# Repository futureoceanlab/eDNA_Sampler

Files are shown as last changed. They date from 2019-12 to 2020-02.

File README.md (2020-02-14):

# eDNA Sampler
This is a project that controls an autonomous eDNA Sampler. There are two modules: ESP8266 based hardware controller and a Django Web Application for interact with ESP8266 wirelessly.

The detailed documentation on architecture, how-to-build, apparatus and testing can be found in eDNA_sampler.pdf in this repository. Furthermore, the link to view the overleaf can be found [here](https://www.overleaf.com/read/nvktmdfzfmym). Please send an email to junsuj@mit.edu if you would like to edit the documentation. 

## Current Apparatus
Feb 2020: We currently have one full-system ready to be disassembled in the lab. We have four packs of batteries and three housings with connectors ready to be assemebled. We have 9 PCB boards and required components to be soldered on the PCB.

# Overview of this repository

## webapp: Web App for online deployment configuration / data retrieval
The program is run on a virtual environment, so install the virtualenv on the machine that will run the Web App.

```bash
pip3 install virtualenv
```

In case that the virtualenv is installed in a path that is not listed (i.e. virtualenv will complain saying that there is no such command), please add the following line to the end of ~/.profile 

```bash
PATH=$PATH:$HOME/.local/bin
```

in eDNA_Sampler/webapp, enter the following line in the terminal

```bash
virtualenv env
source env/bin/activate
``` 

This should activate the virtual environment, and you are ready to install the required packages

```bash
pip3 install -r requirements.txt
```

The webserver hosts' IP address can be found at WLAN0 interface by running the following:

```bash
ifconfig
```

In the webapp directory, run the server

```bash
python3 manage.py runserver 0.0.0.0:5000
```

0.0.0.0 will listen to other devices connected through every interfaces. 5000 is the port, and it can be different as long as it does not coincide with other used ports. 

Finally, check the Firewall if the client cannot access the webapp.

## sampler_mcu: ESP8266 Based Arduino code
The system uses ESP8266 Huzzah from Adafruit and a variety of libraries, and thus, Arduino IDE requires some setup.

In particular, the libraries that need to be installed are:
[ESP8266](https://learn.adafruit.com/adafruit-huzzah-esp8266-breakout/using-arduino-ide), 
[GrooveNfc](https://github.com/Seeed-Studio/Seeed_Arduino_NFC), 
ArduinoJson,
[MS5837](https://github.com/bluerobotics/BlueRobotics_MS5837_Library), 
[TSYS01](https://github.com/bluerobotics/BlueRobotics_TSYS01_Library).

[ESP8266 Huzzah](https://learn.adafruit.com/adafruit-huzzah-esp8266-breakout/using-arduino-ide) explains how to program the device using FTDI converter.

## mechanical
This directory contains designs and schematics for mechanical components of the eDNA Sampler.
Specifically, we have 3D design of the battery housing and acrylic plates for the pvc clamp shell. 
There is also the electronics housing drawing for machining.

## pcb
This is the schematic and layout of the PCB design of the electronics.

## archive
This is a folder with ancient codes and files that were onced developed. They are irrelevant at this point, but archived in this folder.

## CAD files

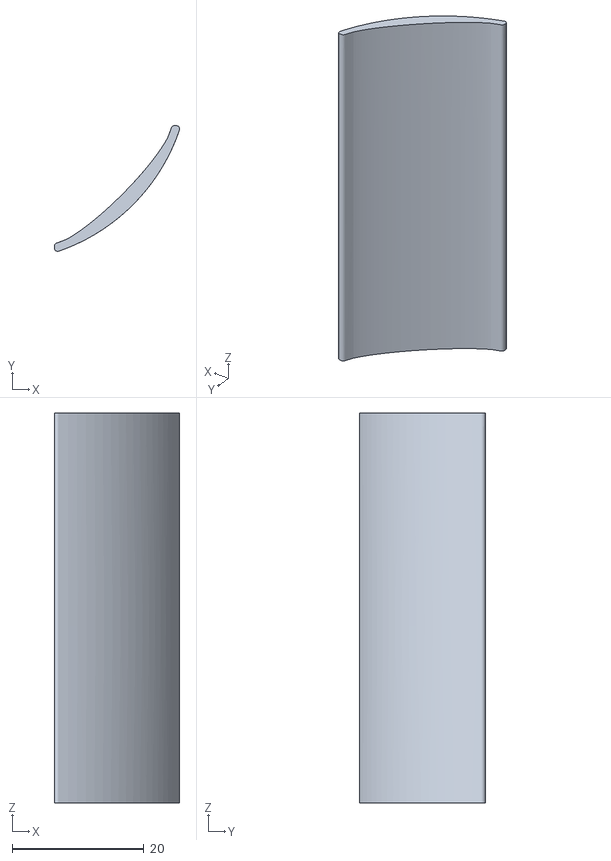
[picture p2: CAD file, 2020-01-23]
mechanical/battery/v4/Cover.stl
19.0 x 19.1 x 59.1

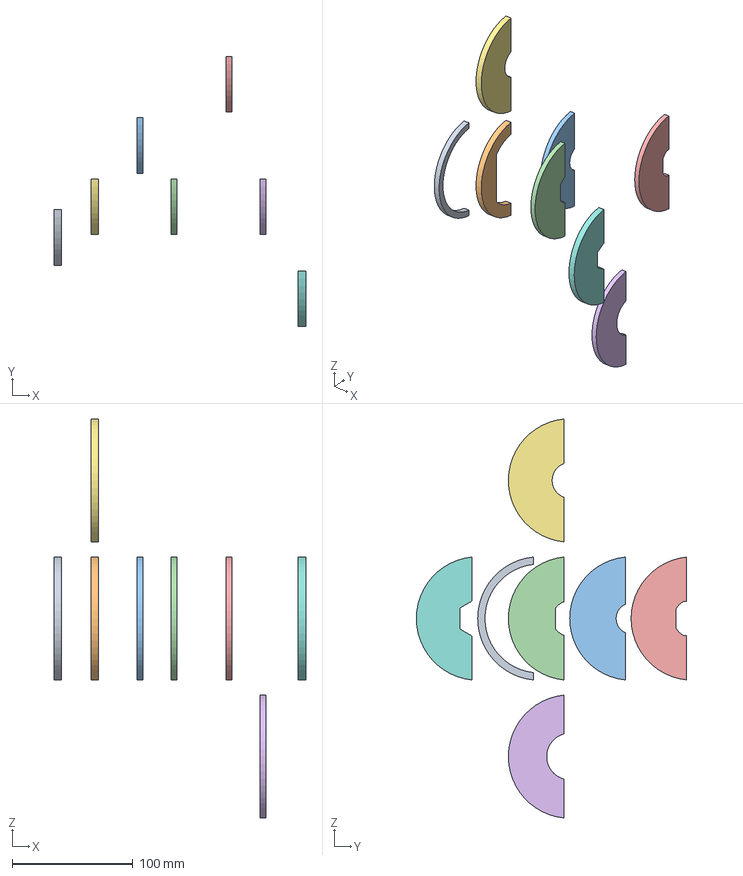
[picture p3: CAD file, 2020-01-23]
mechanical/pvc_shell/PVC_holders v5.step
208.3 x 223.9 x 330.4 mm
range
potted1
connector1
connector2
connector3
connector4
connector2_2
connector4_2

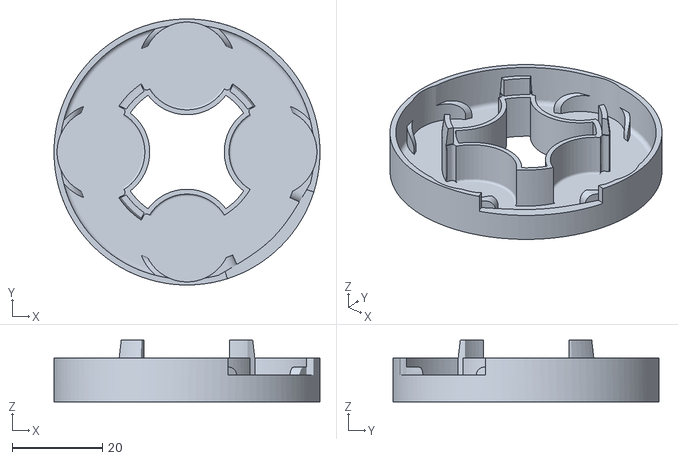
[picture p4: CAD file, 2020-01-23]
mechanical/battery/v4/Battery Cap Bottom.stl
58.9 x 58.9 x 13.7

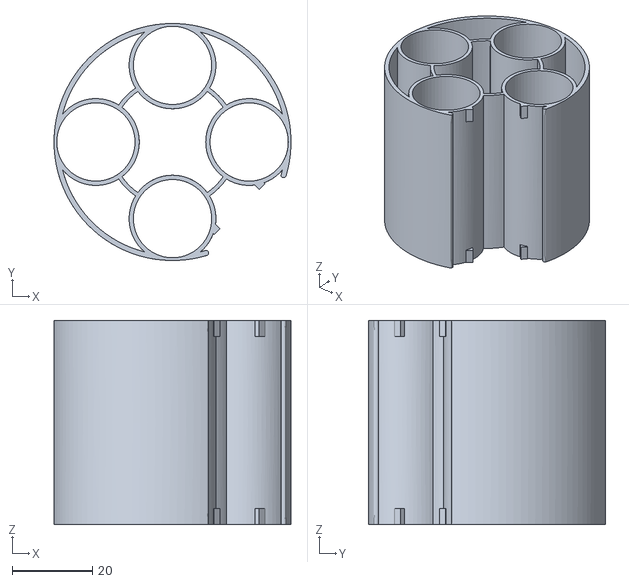
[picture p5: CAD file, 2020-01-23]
mechanical/battery/v4/Battery Holder.stl
58.9 x 58.9 x 50.8

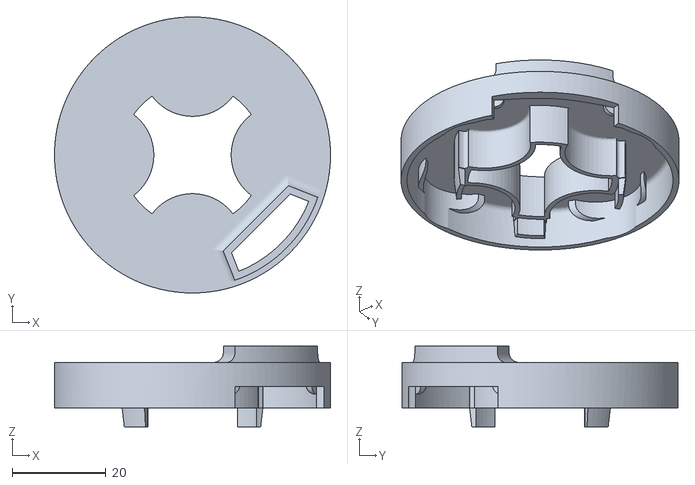
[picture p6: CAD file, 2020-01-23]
mechanical/battery/v4/Battery Cap Top.stl
58.9 x 58.9 x 17.2

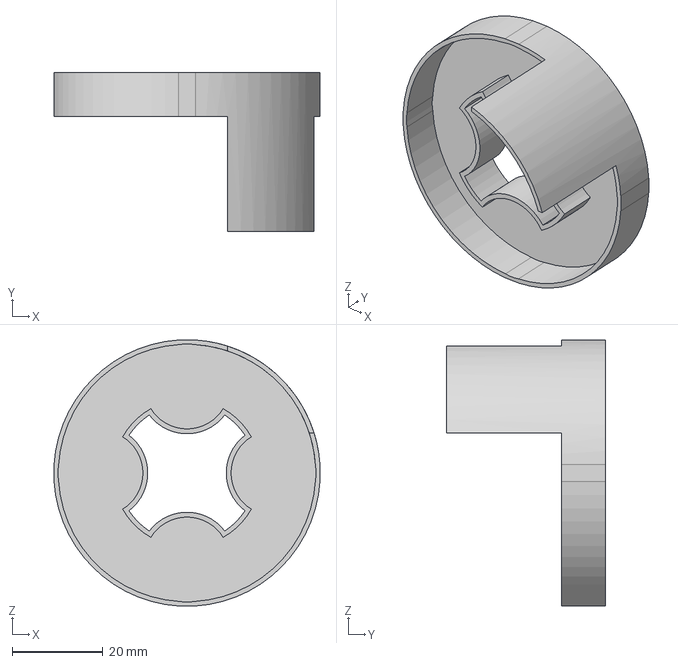
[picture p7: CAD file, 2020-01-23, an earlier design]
mechanical/battery/v3/batter bottom cap.step
58.6 x 35.1 x 58.6 mm

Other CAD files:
mechanical/battery/v3/battery top cap.step
mechanical/battery/v3/batter holder v3.step

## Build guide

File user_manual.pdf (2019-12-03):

Deployment Procedure
Phase 1: setting up the deployment
1. Make sure that the RPI is powered on
2. Plug in the RFID Reader dongle
3. The data from the previous deployment will have been uploaded
4. When the blue light blinks, tap the RFID on the filter onto the antenna
5. By now, the log from the previous deployment will have been uploaded
6. Wait until that green light blinks
7. Refresh the website, then the new deployment with corresponding RFID UID will appear
8. Click on “edit” next to the UID
9. Follow the instruction and specify the deployment details
10. Click “Submit” button at the bottom
11. Wait until the green light stops blinking. At this point, the sampler is properly programmed!
12. Pull out the RFID Reader dongle and wait until deployment
Phase 2: deployment
1. Make sure that the RPI is powered on
2. Plug in the pump unit and wait until the green light is on
3. Deploy!

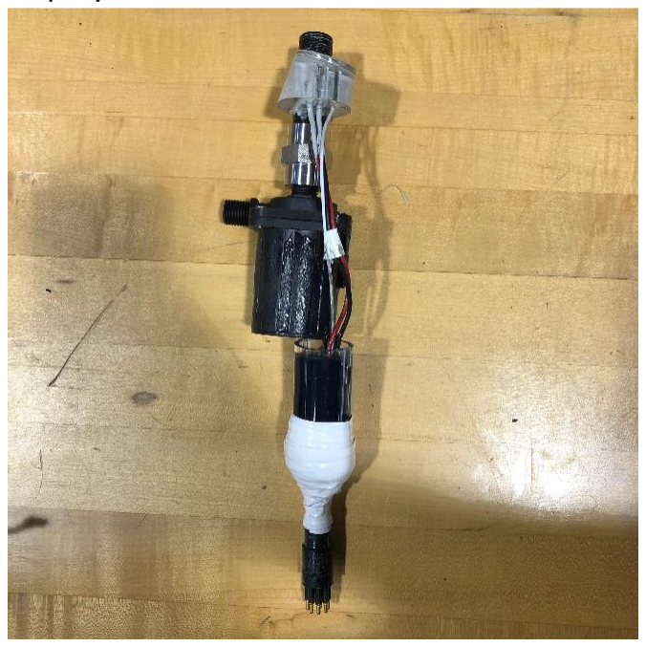
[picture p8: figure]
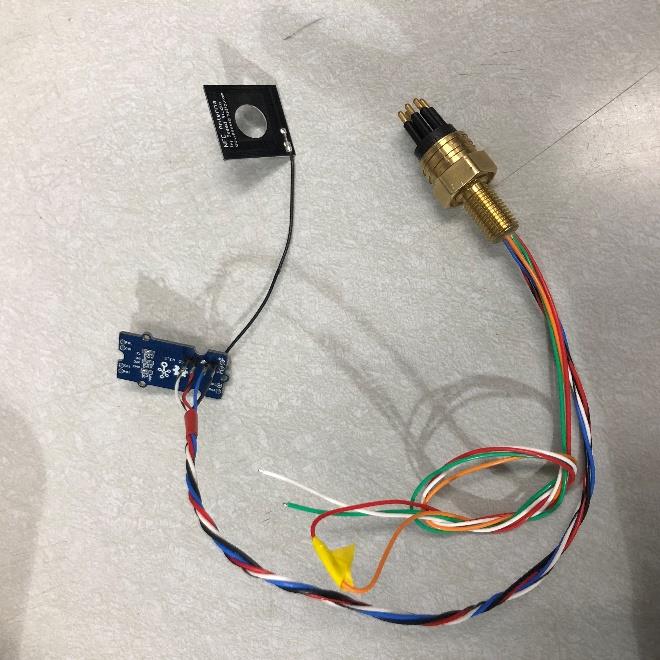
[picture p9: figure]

The pump unit | RFID reader dongle
Notes
- When the RFID reader cannot be properly initialized, which happens quite frequently, it restarts the entire system. It is fine, but you will notice the repeated sequence of the following light actions: blue sparks (turned on), red blinks (set-up), then turn off (failed reader initialization). It will power-cycle until blue light blinks (reader initialized), so please be patient! Unfortunately, we are stuck with this reader for now.
- To re-charge the battery, please plug in the recharging dongle.
- When all three LEDs blink together, something has gone awry in the code as it was setting things up (e.g. I2C devices or WiFi). In this case, please power-cycle by re-plugging in the dongle. The failure will be logged in /log.txt, which will be uploaded the next time it connects to the WiFi.
- Please be aware that there will be some water that flows as the device is primed in water. Hence, using distilled water first is recommended…!

Appendix 1: Programming the ESP8266 HUZZAH

Clone the github repository: https://github.com/futureoceanlab/eDNA_Sampler.git

Please install Arduino IDE and required libraries mentioned in the github.

Upon plugging in the serial cables as shown above, you'll need to put the board into bootload mode. You'll have to do this before each upload. Each button is labeled in the image above.
1. Hold down the GPIO0 button, the red LED will be lit
2. While holding down GPIO0, click the RESET button
3. Release RESET, then release GPIO0
4. When you release the RESET button, the red LED will be lit dimly, this means it's ready to bootload

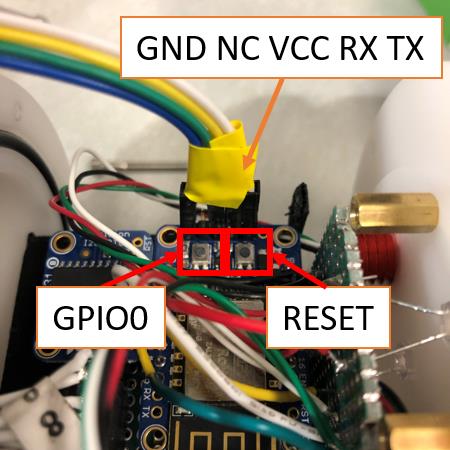
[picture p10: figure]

Now you can upload the code using Arduino IDE

Appendix 2: Programming the webserver (RPI)

Clone the github repository: https://github.com/futureoceanlab/eDNA_Sampler.git

Modify the first line of run_webserver.sh to match the location of the cloned git repository.

Add a line at th end of the following file /etc/rc.local
“sudo bash /home/pi/eDNA_Sampler/run_webserver.sh &”
This should automatically run webserver when the RPI turns on

To set up the RPI to host its own WiFi, follow the instruction until before “add routing and masquerade” section in this link: https://www.raspberrypi.org/documentation/configuration/wireless/access-point.md

ESP8266’s are programmed to look for 192.168.4.1:5000, which is the ip-address and ports of the RPI webserver to access the web application. If that is different, ESP8266 will have to be re-programmed.

# eDNA Sampler Checklist

## Phase 1: Setting up the deployment

1 | Make sure that the RPI is powered on
2 | Plug in the RFID reader dongle
3 | When the blue light blinks, tap the RFID tag on the filter onto the reader antenna
4 | Wait until the green light blinks
5 | Refresh the website
6 | Click on “edit” next to the new UID added
7 | Follow the instruction and specify the deployment details
8 | Click on “submit” button
9 | Wait until the green light stops blinking
10 | Pull out the RFID reader dongle

## Phase 2: Deployment

1 | Make sure that the RPI is on
2 | Plug in the pump unit
3 | Wait until the green light is on
4 | Deploy!

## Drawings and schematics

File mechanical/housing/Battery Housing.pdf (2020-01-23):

A

2 | 3 | 4 | 5 | 6 | 7 | 8

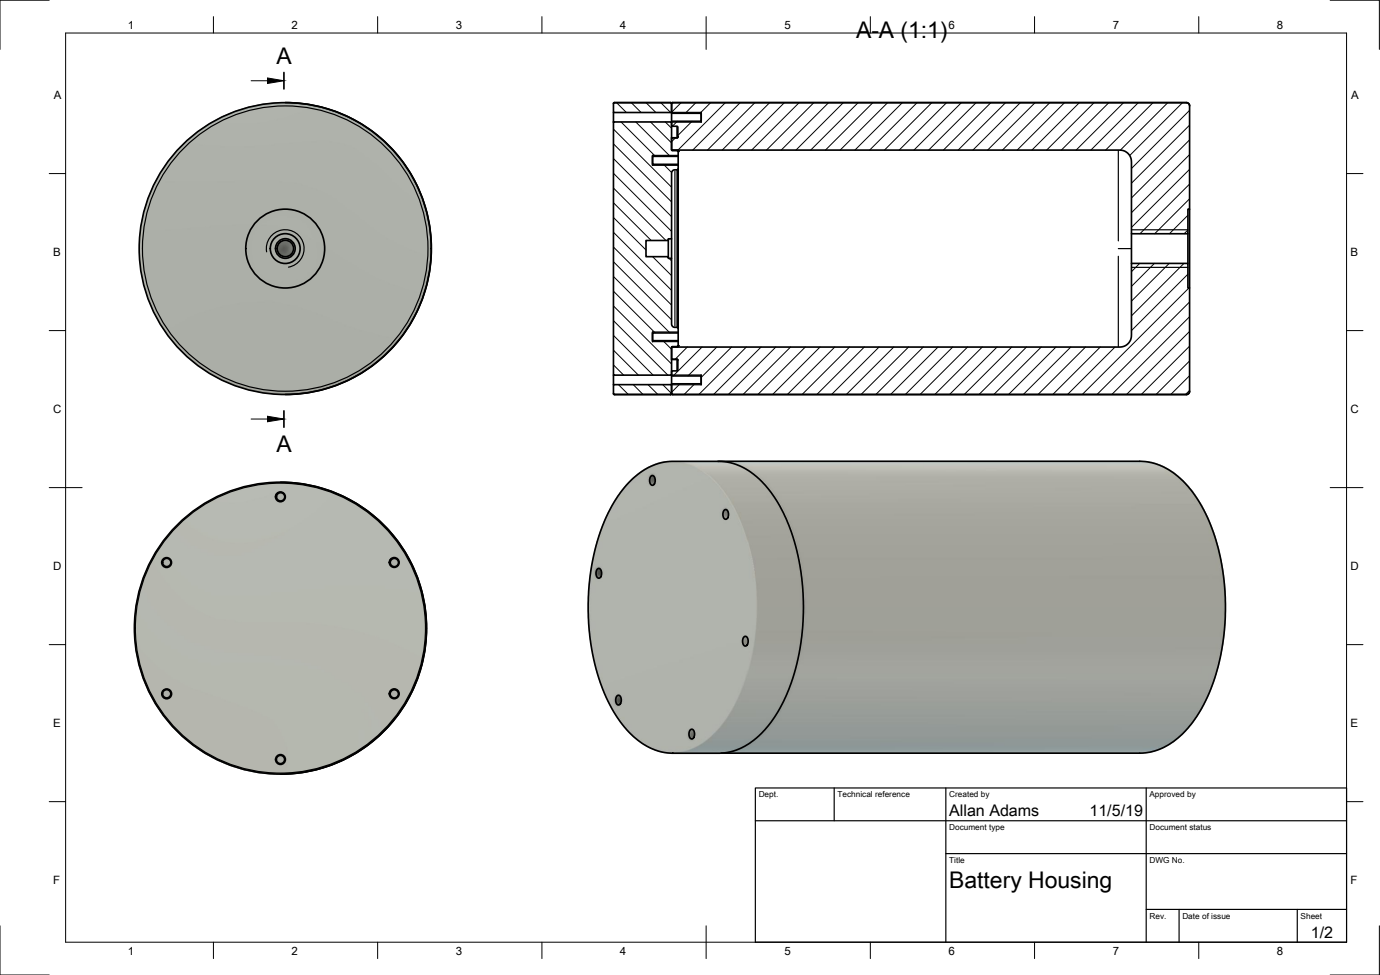
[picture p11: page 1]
Dept.; Technical reference; Created by; Approved by; Document type; Document status; Allan Adams

Title Battery Housing | DWG No.

Rev. | Date of issue | Sheet

A

A

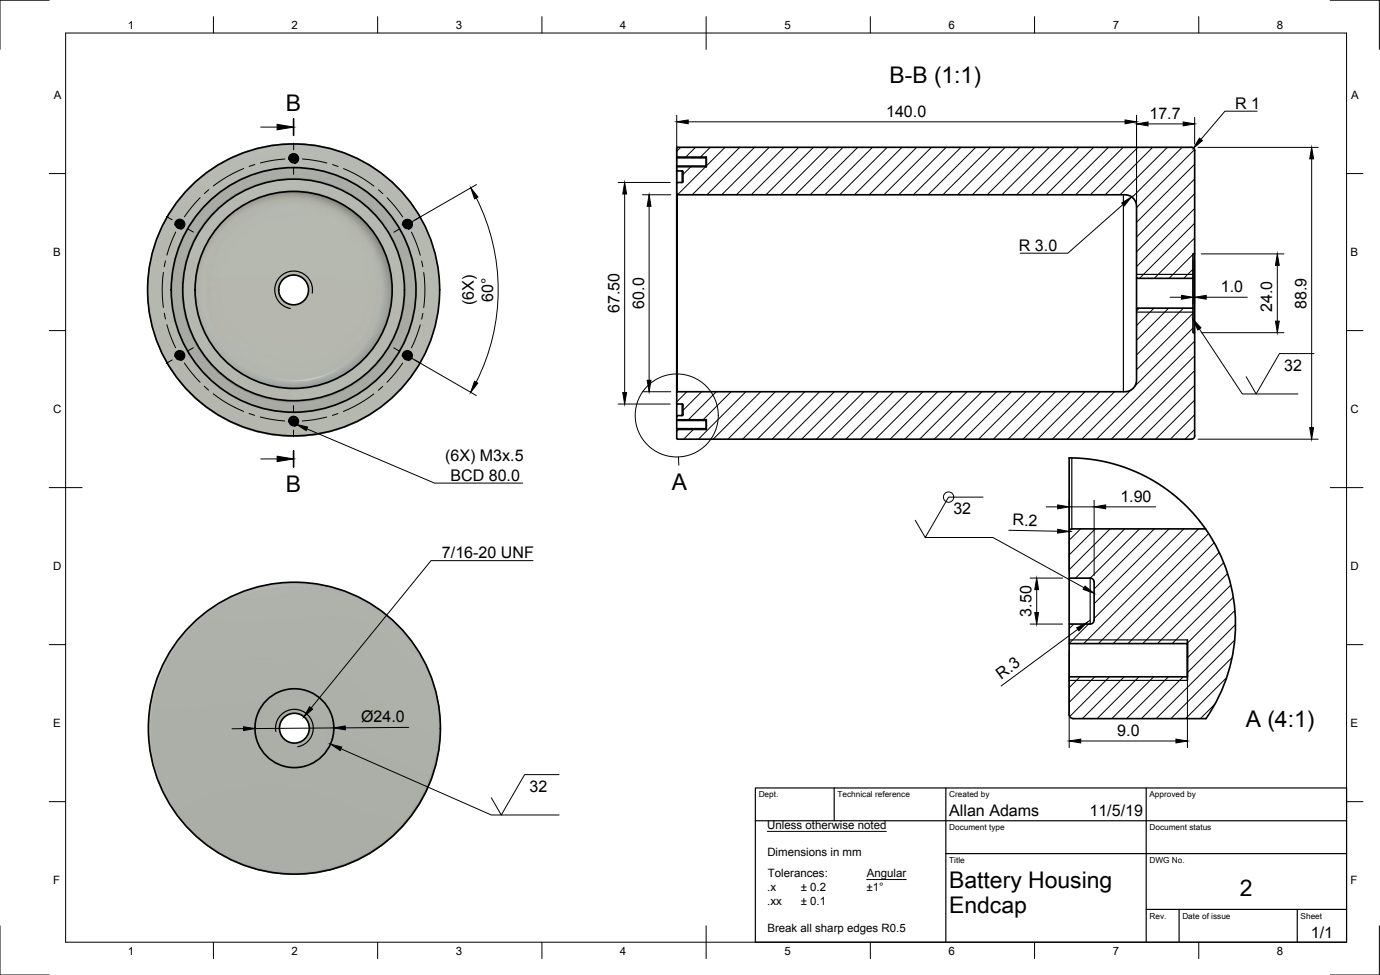
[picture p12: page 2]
Dept.; Technical reference; Created by; Approved by; Document type; Document status; Title; DWG No.; Endcap; 2 Battery Housing; Allan Adams; 7/16-20 UNF; (6X) M3x.5 BCD 80.0; Tolerances:; Angular

Unless otherwise noted

Dimensions in mm

Break all sharp edges R0.5

A

A

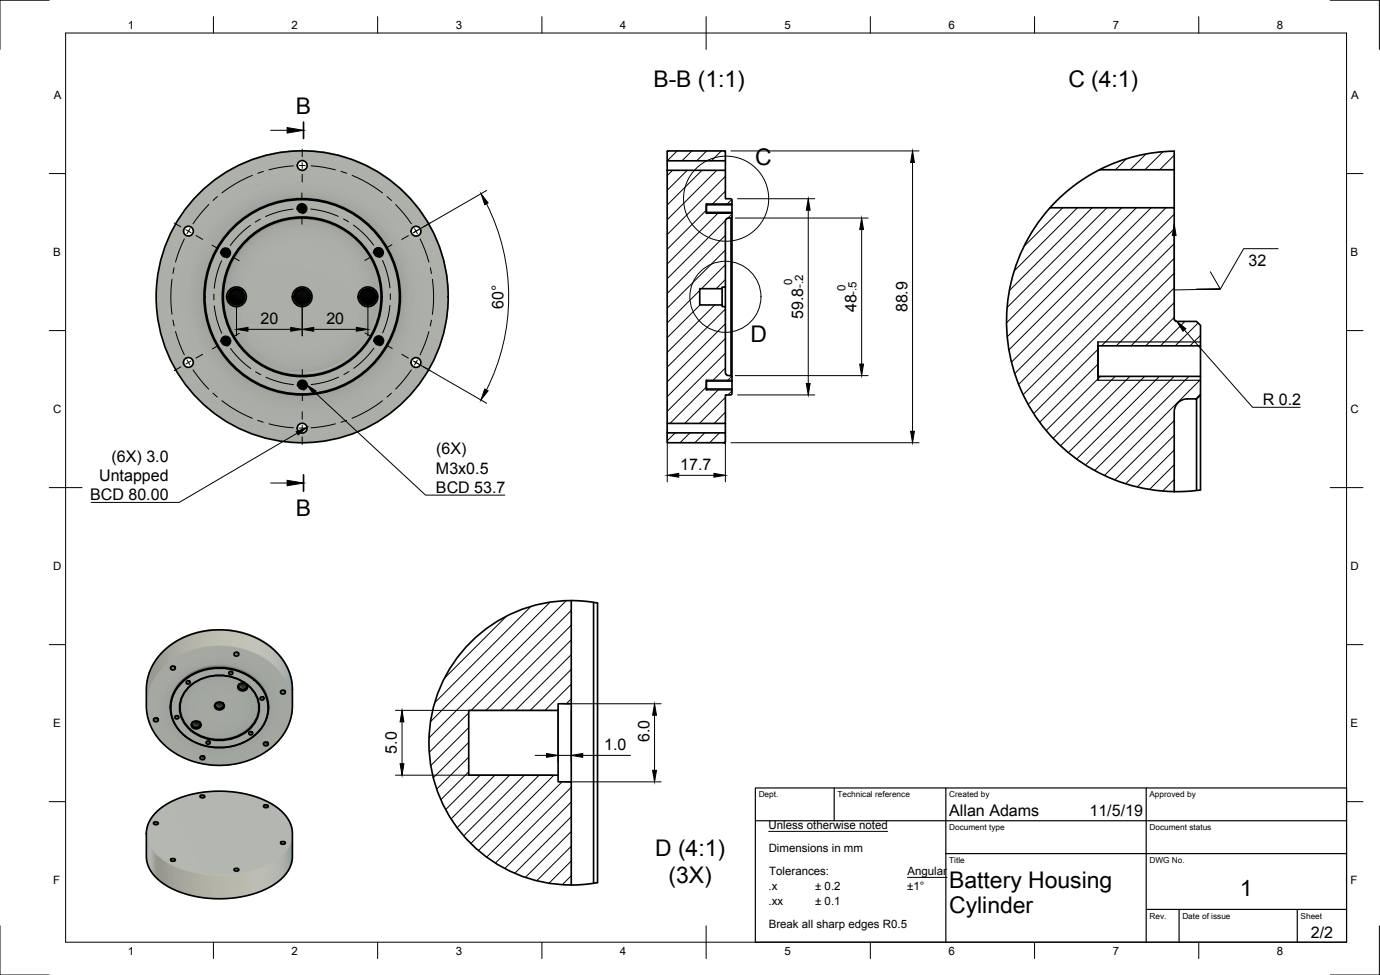
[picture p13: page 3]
Dept.; Technical reference; Created by; Approved by; Document type; Document status; Title; DWG No.; Cylinder; 1 Battery Housing; Allan Adams; (6X) M3x0.5 BCD 53.7; (6X) 3.0 Untapped BCD 80.00; Tolerances:; Angular

Unless otherwise noted
Dimensions in mm
Break all sharp edges R0.5

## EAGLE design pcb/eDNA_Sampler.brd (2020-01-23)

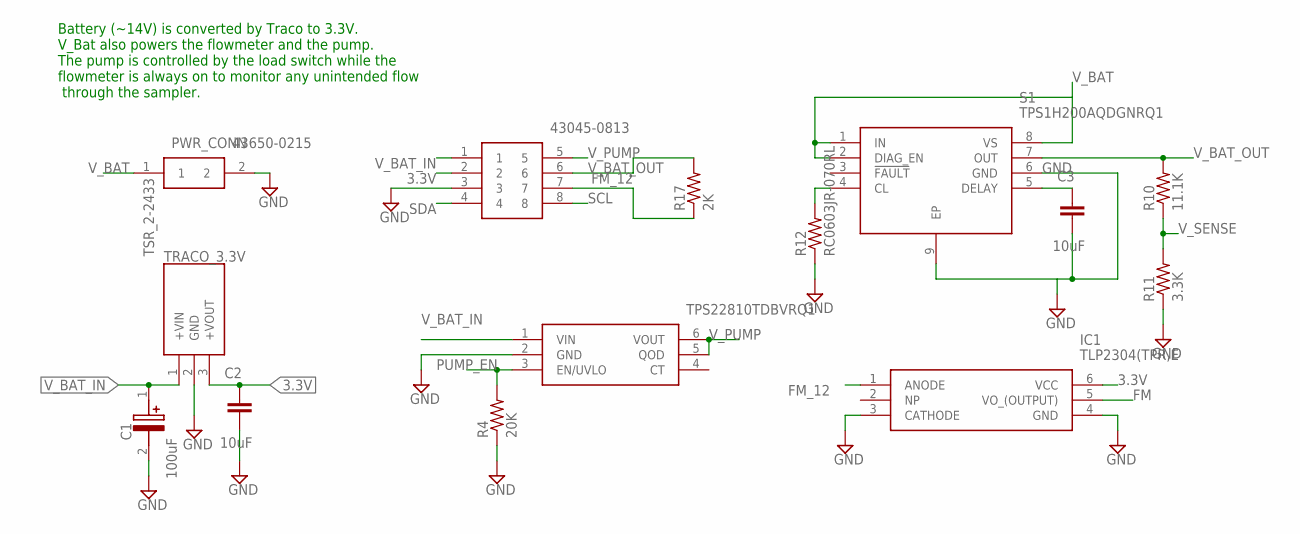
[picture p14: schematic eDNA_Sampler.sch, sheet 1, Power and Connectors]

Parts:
C1: 100uF; CAPPRD250W50D680H1250
C2, C3: 10uF; CAP_0603
IC1: TLP2304(TPR,E; SOIC127P700X230-6N
LOAD_SWITCH: TPS22810TDBVRQ1; SOT95P280X145-6N
PENETRATOR_CONN: 43045-0813
PWR_CONN: 43650-0215; 43650-0217
R4: 20K; RES_0603
R10: 11.1K; RES_0603
R11: 3.3K; RES_0603
R12: RC0603JR-070RL; RES_0603
R17: 2K; RES_0603
S1: TPS1H200AQDGNRQ1; SOP65P490X110-9N
TRACO_3.3V: TSR_2-2433; TSR-2

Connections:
3.3V: C2.1, IC1.6 (VCC), PENETRATOR_CONN.2, TRACO_3.3V.3 (+VOUT); also elsewhere on the board
FM: IC1.5 (VO_(OUTPUT)); also elsewhere on the board
FM_12: IC1.1 (ANODE), PENETRATOR_CONN.7, R17.1
GND: C1.2 (-), C2.2, C3.2, IC1.3 (CATHODE), IC1.4 (GND), LOAD_SWITCH.2 (GND), PENETRATOR_CONN.3, PWR_CONN.2, R4.1, R11.1, R12.1, S1.6 (GND), S1.9 (EP), TRACO_3.3V.2 (GND); also elsewhere on the board
unnamed: R12.2, S1.4 (CL)
unnamed: C3.1, S1.5 (DELAY)
PUMP_EN: LOAD_SWITCH.3 (EN/UVLO), R4.2; also elsewhere on the board
SCL: PENETRATOR_CONN.8; also elsewhere on the board
SDA: PENETRATOR_CONN.4; also elsewhere on the board
V_BAT: PWR_CONN.1, S1.1 (IN), S1.2 (DIAG_EN), S1.8 (VS)
V_BAT_IN: C1.1 (+), LOAD_SWITCH.1 (VIN), PENETRATOR_CONN.1, TRACO_3.3V.1 (+VIN)
V_BAT_OUT: PENETRATOR_CONN.6, R10.2, R17.2, S1.7 (OUT)
V_PUMP: LOAD_SWITCH.5 (QOD), LOAD_SWITCH.6 (VOUT), PENETRATOR_CONN.5
V_SENSE: R10.1, R11.2; also elsewhere on the board

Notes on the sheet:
Battery (~14V) is converted by Traco to 3.3V. V_Bat also powers the flowmeter and the pump. The pump is controlled by the load switch while the flowmeter is always on to monitor any unintended flow through the sampler.

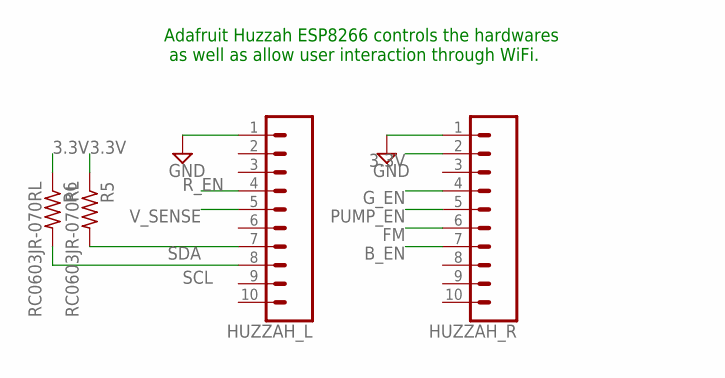
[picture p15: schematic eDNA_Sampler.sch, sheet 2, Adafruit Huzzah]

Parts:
HUZZAH_L: CONN_10"; 1X10
HUZZAH_R: CONN_10"; 1X10
R5, R6: RC0603JR-070RL; RES_0603

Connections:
3.3V: HUZZAH_R.2, R5.1, R6.1; also elsewhere on the board
B_EN: HUZZAH_R.7; also elsewhere on the board
FM: HUZZAH_R.6; also elsewhere on the board
GND: HUZZAH_L.1, HUZZAH_R.1; also elsewhere on the board
G_EN: HUZZAH_R.4; also elsewhere on the board
PUMP_EN: HUZZAH_R.5; also elsewhere on the board
R_EN: HUZZAH_L.4; also elsewhere on the board
SCL: HUZZAH_L.8, R6.2; also elsewhere on the board
SDA: HUZZAH_L.7, R5.2; also elsewhere on the board
V_SENSE: HUZZAH_L.5; also elsewhere on the board

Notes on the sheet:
Adafruit Huzzah ESP8266 controls the hardwares as well as allow user interaction through WiFi.

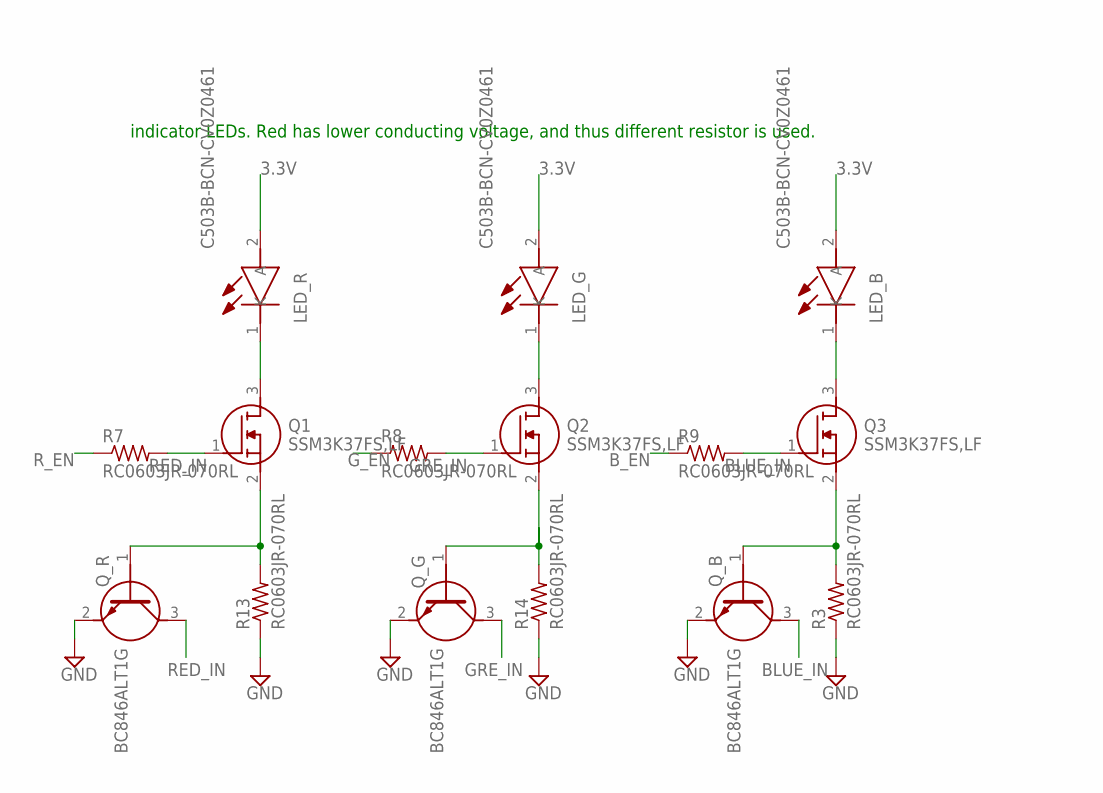
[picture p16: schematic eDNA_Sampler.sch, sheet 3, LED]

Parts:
LED_B: C503B-BCN-CV0Z0461; C503B-BCN
LED_G: C503B-BCN-CV0Z0461; C503B-BCN
LED_R: C503B-BCN-CV0Z0461; C503B-BCN
Q1, Q2, Q3: SSM3K37FS,LF; SSM3K37FSLF
Q_B: BC846ALT1G; SOT95P237X111-3N
Q_G: BC846ALT1G; SOT95P237X111-3N
Q_R: BC846ALT1G; SOT95P237X111-3N
R3, R7, R8, R9, R13, R14: RC0603JR-070RL; RES_0603

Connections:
3.3V: LED_B.2 (A), LED_G.2 (A), LED_R.2 (A); also elsewhere on the board
BLUE_IN: Q3.1 (G), Q_B.3 (C), R9.2
B_EN: R9.1; also elsewhere on the board
GND: Q_B.2 (E), Q_G.2 (E), Q_R.2 (E), R3.1, R13.1, R14.1; also elsewhere on the board
GRE_IN: Q2.1 (G), Q_G.3 (C), R8.2
G_EN: R8.1; also elsewhere on the board
unnamed: LED_R.1 (K), Q1.3 (D)
unnamed: LED_G.1 (K), Q2.3 (D)
unnamed: Q2.2 (S), Q_G.1 (B), R14.2
unnamed: Q1.2 (S), Q_R.1 (B), R13.2
unnamed: Q3.2 (S), Q_B.1 (B), R3.2
unnamed: LED_B.1 (K), Q3.3 (D)
RED_IN: Q1.1 (G), Q_R.3 (C), R7.2
R_EN: R7.1; also elsewhere on the board

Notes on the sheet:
indicator LEDs. Red has lower conducting voltage, and thus different resistor is used.

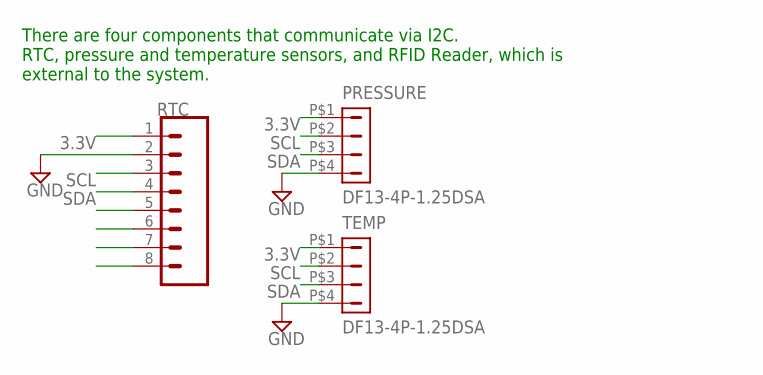
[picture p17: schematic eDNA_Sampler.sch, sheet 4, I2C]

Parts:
PRESSURE: DF13-4P-1.25DSA
RTC: CONN_08"; 1X08
TEMP: DF13-4P-1.25DSA

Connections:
3.3V: PRESSURE.P$1 (1), RTC.1, TEMP.P$1 (1); also elsewhere on the board
GND: PRESSURE.P$4 (4), RTC.2, TEMP.P$4 (4); also elsewhere on the board
SCL: PRESSURE.P$2 (2), RTC.3, TEMP.P$2 (2); also elsewhere on the board
SDA: PRESSURE.P$3 (3), RTC.4, TEMP.P$3 (3); also elsewhere on the board

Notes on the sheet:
There are four components that communicate via I2C. RTC, pressure and temperature sensors, and RFID Reader, which is external to the system.

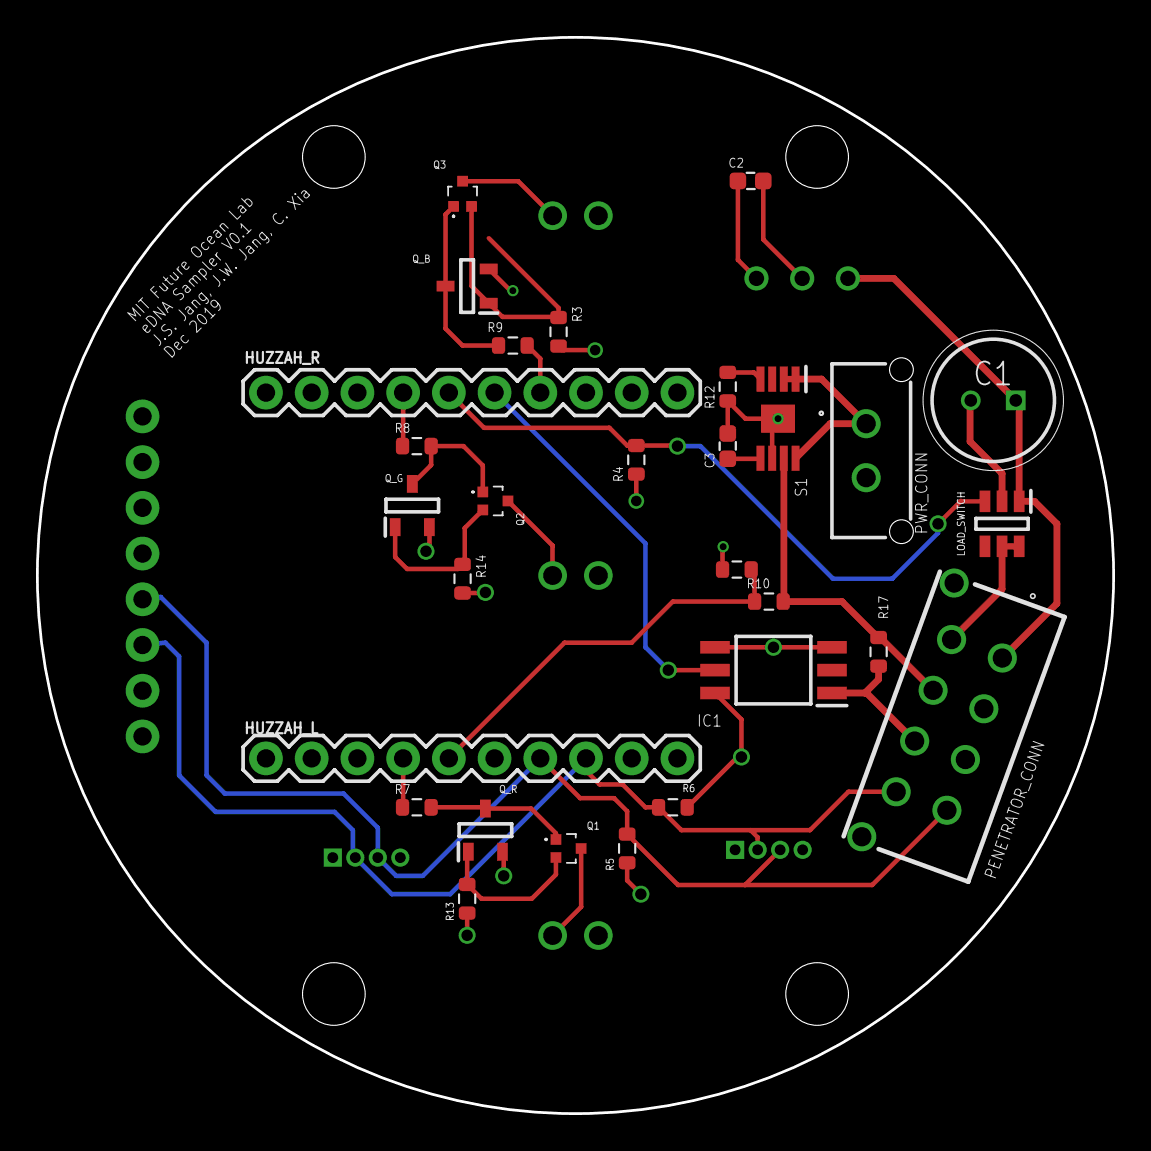
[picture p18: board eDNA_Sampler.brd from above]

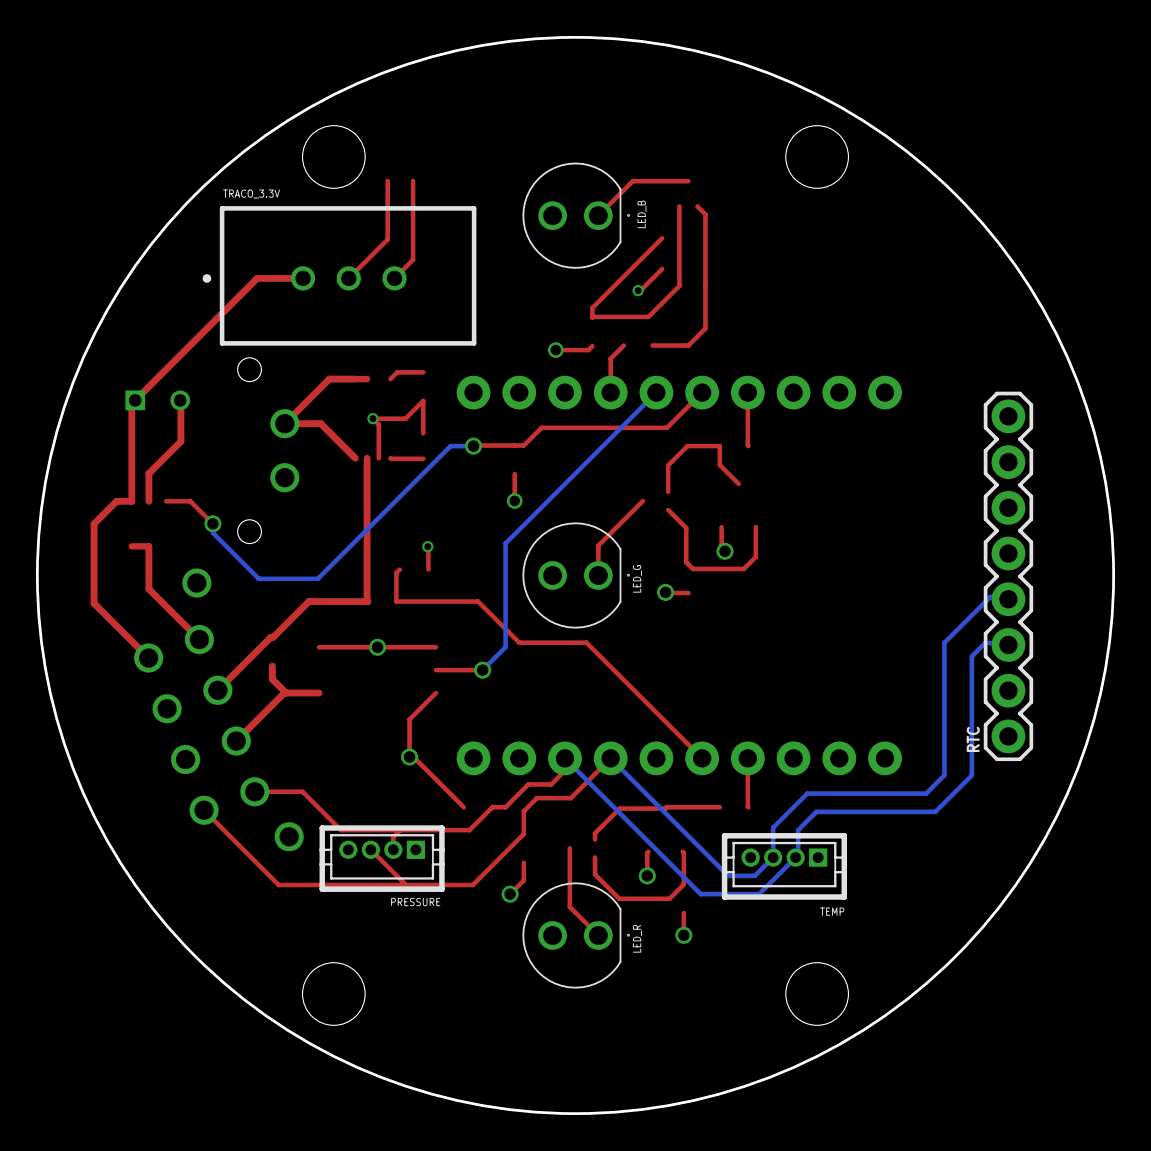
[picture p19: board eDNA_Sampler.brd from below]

Board: 4 copper layers, 59.8 x 59.8 mm, 36 parts (7 on the bottom side), 26 nets.

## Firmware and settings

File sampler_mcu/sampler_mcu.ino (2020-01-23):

/**
 * eDNA Sampler: ESP8266 based eDNA sampler / relevant sensor controller
 * January 2020
 * Authors: JunSu Jang
 *        
 *      [Descriptions]
 * 
 *  This eDNA Sampler will sample eDNA at specified depth of the ocean by
 * using a off-the-shelf pump. It keeps track of the relevant data 
 * (i.e. pressure, temperature, water flow and realtime)
 * 
 * 1. Deployment configuration
 *  a) Set up I2C devices (RTC, RFID reader, pressure and temperature sensors)
 *  b) Connect to local WiFi and upload collected data if exists
 *     Delete the uploaded datafile
 *  c) Wait for a eDNA filter's RFID tag to be tagged
 *  d) Upon tagging, create a deployment on the local webserver and
 *     wait for deployment configurations
 * 
 *     Pump Starting Conditions
 *     i) "Target Depth" (meters)
 *        - Pump at this depth within the "Depth Band"
 *     ii) "Target Temperature" (Celcius)
 *        - Pump in this thermocline within the "Temperature Band"
 *     iii) "Wait Time" upon 2m submersion (minutes):
 *        - Depending on the deployment, it may not reach the depth, 
 *          in which case, we start pumping after "Wait Time"
 *
 *     Pump Terminate Conditions
 *     i) "Target Flow Volume" (Liter)
 *        - We will pump water until target volume has been passed 
 *          through the filter
 *     ii) "Minimum Flowrate" (Liters/min)
 *        - Stop when the filter is clogged
 *     iii) "Target Flow Duration" (minutes)
 *        - Our filter may be full before the target volume has been met. 
 *          We stop pumping after specified "Target Flow Duration"
 * 2. Start logging time, pressure, temperature, volume and flowrate at 1Hz and
 *    log it to the file created
 * 3. Control the pump according to the configuration provided
 * 4. Keep measure flow, time, pressure and temperature at 1Hz until the power is off
 * 
 *      [LED Encoding]
 * 
 * - Power on --> RED on
 * - Wait for RFID --> BLUE blink
 * - Wait for deployment config --> GREEN blink
 * - All ready -- GREEN on
 * 
 *      [SPIFFS data filesystem]
 * 
 * Filename: [RFID_UID].txt
 * Logged data: [unix timestamp],[pressure],[temperature],[volume],[flowrate]\r\n
 * There is also an intenral log file that allows users to debug any issues
 * during deployment. 
*/

// Native libraries
#include <Wire.h>
#include <Ticker.h>
#include <String.h>
#include <FS.h>
#include <NfcAdapter.h>
#include <PN532/PN532/PN532.h>
#include <PN532/PN532_I2C/PN532_I2C.h>
#include <ArduinoJson.h>
#include <limits.h>
// External libraries
#include "TimeLib.h"
#include "RTClib.h"
#include "MS5837.h"
#include "KellerLD.h"
#include "TSYS01.h"
// Custom libraries
#include "src/sampler.h"                // verifies conditions for pump control
#include "src/samplerHelper.h"          // helper functions
#include "src/samplerWiFi.h"            // module that handles WiFi connection/comms
#include "src/samplerGlobals.h"         // contains all of the global variables

/**
 *  Data variables
 */
// Flowmeter
volatile uint32_t flowCounter = 0;  // flowmeter interrupt update variable
volatile uint32_t curTicks = 0;     // Stamped number of accumulated flowmeter ticks 
volatile uint32_t curTime;          // current time
float curDepth = 0.f;               // depth in meters
float curTemperature = 0.f;         // temperature in Celcius
float curFlowrate = 0.f;            // flowrate in L/min

/**
 * Peripherals
 */
// RTC
RTC_DS3231 rtc;
// Pressure
#ifdef IS_MS5837
MS5837 pSensor;
#else // Keller Sensor
KellerLD pSensor;
#endif
// Temperature
TSYS01 tSensor;
// RFID
PN532_I2C pn532_i2c(Wire);
NfcAdapter rfidReader = NfcAdapter(pn532_i2c);
String eDNA_UID;                    // UID of the RFID tag attached to sampler
// Timer for 1Hz log / LED
Ticker ticker;
// Pump
uint32_t pumpDuration = 0;          // number of seconds after pump started
                                    // to calculate initial pump max. flowrate

/**
 *  flags
 */
uint8_t fSamplerStatus = NOT_READY;
uint8_t fPumpStatus = IDLE;
uint8_t fLogData = NOT_READY;

/**
 *  Logger
 */
String dataFilePath;
String logFilePath = "/log.txt";

/**
 *  Sampler helper instance declaration
 */
Sampler sampler = Sampler();
SamplerWiFi samplerWiFi = SamplerWiFi();

/**
 * Helper function declartions
 */
// setup relevant GPIO pins
void setupPins(void);
// Setup I2C devices
void setupI2c(void);

// Flowmeter Interrupt handler
static void ICACHE_RAM_ATTR isr_flowmeter(void);
// stamp the current flowmeter reading and time
void stampTicks(void);
// read all the peripheral data and store them in global curX variables
void readData(void);
// write the data onto the data file
void writeData(void);

// Wait for RFID to be read and set the eDNA_UID
void waitRFID(void);
// Control the pump action based on the conditions
void controlPump(void);

// synchornize the RTC with the time of the webserver
void synchronizeRTC(void);
// Check if deployment has been configured (i.e. RFID scanned)
uint8_t getDeploymentStatus(void);
// Query the deployment configuration from the webserver
void getDeploymentConfiguration(void);
// Upload data file, broken into chunks, to the webserver
void uploadExistingData(void);
// Similarly, upload log file
void uploadExistingLog(void);
// Helper function to concat data file path String
String createDataFilePath(void);

// Trigger the ticker to measure data every second
void startMeasuringData(void);
// line to log internally any information
void internalLogLine(String logData);
// Wrapper for outputing the message to the correct output
void outputDebugMessage(String msg);


/**
 *     setup()
 * 
 *   Setup GPIO Pins
 *   Setupt I2C
 *   Connect to WiFi
 *   If there is file, send it over and delete
 *   Wait for RFID
 *   Wait for Deployment configuration
 *   Create file
 *   Start collecting data
 *   
 * 
 */
void setup() {
    #ifdef DEBUG
    Serial.begin(9600);
    #endif
    SPIFFS.begin();

    setupPins();
    turnOnLED(LED_PWR);
    outputDebugMessage("Trying to connect to WiFi");
    uint8_t online = samplerWiFi.connectWiFi();
    if (!online) {
        internalLogLine("Wifi connection failed after 10 attempts!");
        flagErrorLED();
    }
    outputDebugMessage("WiFi connected");
    outputDebugMessage("Setting up I2C...");
    
    setupI2c();
    synchronizeRTC();
    uploadExistingData();
    uploadExistingLog();
    fSamplerStatus = getDeploymentStatus();

    switch (fSamplerStatus) {
        case NOT_READY:
            rfidReader.begin();
            blinkSingleLED(LED_RDYB, 500);
            waitRFID();
            turnOnLED(LED_RDYB);
            samplerWiFi.uploadNewDeployment(eDNA_UID);
            turnOffLED(LED_RDYB);
            blinkSingleLED(LED_RDYG, 500);
            getDeploymentConfiguration();
            break;
        case READY:
            blinkSingleLED(LED_RDYG, 500);
            getDeploymentConfiguration();
            dataFilePath = createDataFilePath();
            startMeasuringData();
            outputDebugMessage("Wait for deployment...");
            break;
        default:
            break;
    }
    turnOnLED(LED_RDYG);
}

/***********************************************************
 * 
 *     loop()
 * 
 *   If log data flag is set, do the following:
 *    - read from sensors
 *    - Save the data
 *   Depending on famplerStatus, act accordingly
 *   READY:
 *      Waiting to be deployed underwater (below 2m)
 *   DEPLOYED:
 *      Control the pump until surface out of the water (above 2m)
 *   COMPLETE:
 *      Out of water, just log the data until powered off
 * 
 */
void loop() {
    // Log data and check device status/action every second
    if (fLogData == READY) {
        readData();
        writeData();
        fLogData = NOT_READY;
        switch (fSamplerStatus) {
            case READY:
                #ifdef DEBUG
                sampler.setDiveStartTime(curTime);
                fSamplerStatus = DEPLOYED;
                outputDebugMessage("Deployed");
                #else
                if (curDepth > MIN_DEPTH) {
                // Finally, the device is submerged underwater!
                    sampler.setDiveStartTime(curTime);
                    // Turn off all of the LEDs in the water
                    turnOffLED(LED_PWR);
                    turnOffLED(LED_RDYG);
                    fSamplerStatus = DEPLOYED;
                }
                #endif
                break;
            case DEPLOYED:
                controlPump();
                #ifndef DEBUG
                if (curDepth <= MIN_DEPTH) {
                // Out of the water
                    fSamplerStatus = COMPLETE;
                    // Turn the LEDs back on
                    turnOnLED(LED_PWR);
                    turnOnLED(LED_RDYG);
                    // Turn off the pump just in case
                    digitalWrite(PUMP_PIN, LOW);
                }
                #endif
                break;
            case COMPLETE:
            // Nothing to do here but wait until power-cycled to upload
            // the newly collected data
                break;
            default:
                break;
        }
    }
}

void readData() {
    sampler.updateCurrentFlowrate(curTicks);
    curFlowrate = sampler.getCurFlowrate();
    // Pressure / Depth
    pSensor.read();
    curDepth = pSensor.depth();
    // Temperature
    tSensor.read();
    curTemperature  = tSensor.temperature();
}

void writeData() {
    // Write data to the data log file
    File dataFile = SPIFFS.open(dataFilePath, "a+");
    dataFile.print(curTime);
    dataFile.print(',');
    dataFile.print(curDepth);
    dataFile.print(',');
    dataFile.print(curTemperature);
    dataFile.print(',');
    dataFile.print(curTicks);
    dataFile.print(',');
    dataFile.println(curFlowrate);
    dataFile.close();
    #ifdef DEBUG
    Serial.print(curTime);
    Serial.print(", ");
    Serial.print(curDepth);
    Serial.print(", ");
    Serial.print(curTemperature);
    Serial.print(", ");
    Serial.print(curTicks);
    Serial.print(", ");
    Serial.println(curFlowrate);
    #endif
}

void controlPump() {
    uint8_t pumpAction = sampler.checkPumpTrigger(curDepth, curTemperature, curTime, curTicks, pumpDuration);
    if (fPumpStatus == IDLE && pumpAction == PUMP_ON) {
        sampler.setPumpStartTime(curTime);
        digitalWrite(PUMP_PIN, HIGH);
        fPumpStatus = RUNNING;
        outputDebugMessage("PUMP ON");
    } else if (fPumpStatus == RUNNING && pumpAction == PUMP_OFF) {
        digitalWrite(PUMP_PIN, LOW);
        fPumpStatus = IDLE;
        outputDebugMessage("PUMP OFF");
    }
    // After 10 seconds since pumping, measure the maximum flowrate
    if (fPumpStatus == RUNNING) {
        if (pumpDuration == NUM_PUMP_COUNTS) {
            sampler.computeMaxFlowrate(curTicks);
        }
        pumpDuration++;
    }
}


String createDataFilePath() {
    String dataFile = "/";
    dataFile.concat(eDNA_UID);
    dataFile.concat(".txt");
    #ifdef DEBUG
    Serial.print("Data file name: ");
    Serial.println(dataFile);
    #endif
    return dataFile;
}


void setupPins() {
    // GPIO for LED Indicators (OUTPUT)
    pinMode(LED_PWR, OUTPUT);
    pinMode(LED_RDYB, OUTPUT);
    pinMode(LED_RDYG, OUTPUT);

    turnOffLED(LED_PWR);
    turnOffLED(LED_RDYB);
    turnOffLED(LED_RDYG);

    // GPIO for controlling Power to the pump
    pinMode(PUMP_PIN, OUTPUT);
    digitalWrite(PUMP_PIN, LOW);

    // Flowmeter
    pinMode(FM_PIN, INPUT_PULLUP);
    attachInterrupt(FM_PIN, isr_flowmeter, FALLING);

    outputDebugMessage("Pins set");
}


void setupI2c() {
    Wire.begin();

    // RTC
    if (!rtc.begin()) {
        outputDebugMessage("Couldn't find RTC.");
        flagErrorLED();
    }
    // RTC has a new/replaced battery
    if (rtc.lostPower()) {
        outputDebugMessage("RTC lost power, lets set the time!");
        // following line sets the RTC to the date & time this sketch was compiled 
        rtc.adjust(DateTime(F(__DATE__), F(__TIME__)));
    }
    outputDebugMessage("RTC setup successful.");
    // Temperature 
    tSensor.init();
    outputDebugMessage("Temperature setup SUCCESS");

    // Pressure sensor
    #ifdef IS_MS5837
    uint8_t p_init_attempts = 0;
    while (!pSensor.init() && p_init_attempts < 5) {
        delay(1000); 
        p_init_attempts++;
    }
    if (p_init_attempts == 5) {
        outputDebugMessage("Sensor MS5837 setup failed after 5 attempts.");
        flagErrorLED();
    }
    #else
    pSensor.init();
    #endif

    outputDebugMessage("Pressure sensor setup successful.");
    outputDebugMessage("I2C setup complete!");
}


void waitRFID(void) {
  outputDebugMessage("RFID Waiting");
  // Block until there is a tag present
  while (!(rfidReader.tagPresent())) {}

  NfcTag tag = rfidReader.read();
  // Set UID parameter
  eDNA_UID = tag.getUidString();
  eDNA_UID.replace(" ", "");
  outputDebugMessage(eDNA_UID);
}


static void ICACHE_RAM_ATTR isr_flowmeter() {
  flowCounter++;
}

void startMeasuringData() {
    outputDebugMessage("**START LOGGING DATA");
    ticker.attach_ms(1000, stampTicks);
}

void stampTicks() {
  cli();
  curTicks = flowCounter;
  curTime = rtc.now().unixtime();
  sei();
  fLogData = READY;
}


void internalLogLine(String logData) {
  File logFile = SPIFFS.open(logFilePath, "a+");
  logFile.print(rtc.now().unixtime());
  logFile.print(": ");
  logFile.println(logData);
  logFile.close();
}

void getDeploymentConfiguration() {
    while (!sampler.isValidUserConfig()) {
        DynamicJsonDocument jsonBuffer = samplerWiFi.queryDeploymentConfiguration(eDNA_UID);

        // Parameters for deployment configuration
        float minFlowrate = jsonBuffer["min_flowrate"]; // L/min
        float targetDepth = jsonBuffer["depth"];
        float depthBand = jsonBuffer["depth_band"];
        float targetTemperature = jsonBuffer["temperature"];
        float temperatureBand = jsonBuffer["temp_band"];
        uint32_t waitPumpEnd = jsonBuffer["wait_pump_end"]; // min
        uint32_t waitPumpStart = jsonBuffer["wait_pump_start"]; // min
        uint32_t targetFlowVol = jsonBuffer["flow_volume"]; // ticks
        uint32_t ticksPerLiter = jsonBuffer["ticks_per_L"];
        #ifdef DEBUG
        Serial.print(minFlowrate);
        Serial.print(", ");
        Serial.print(targetDepth);
        Serial.print(", ");
        Serial.print(depthBand);
        Serial.print(", ");
        Serial.print(targetTemperature);
        Serial.print(", ");
        Serial.print(temperatureBand);
        Serial.print(", ");
        Serial.print(waitPumpEnd);
        Serial.print(", ");
        Serial.print(waitPumpStart);
        Serial.print(", ");
        Serial.print(targetFlowVol);
        Serial.print(", ");
        Serial.println(ticksPerLiter);
        #endif
        sampler.setDeploymentConfig(minFlowrate, 
                                    targetDepth,
                                    depthBand,
                                    targetTemperature,
                                    temperatureBand,
                                    waitPumpEnd,
                                    waitPumpStart,
                                    targetFlowVol,
                                    ticksPerLiter);  
        delay(1000);

    }

}

uint8_t getDeploymentStatus() {
    DynamicJsonDocument jsonBuffer = samplerWiFi.checkDeploymentStatus();

    uint8_t deploymentStatus = jsonBuffer["status"];
    if (deploymentStatus == READY) {
        eDNA_UID = jsonBuffer["eDNA_UID"].as<String>();
        outputDebugMessage(eDNA_UID);
    }
    return deploymentStatus;
}

void synchronizeRTC() {
    time_t tOnline = samplerWiFi.getTimeOnline();
    #ifdef DEBUG
    Serial.print("Time: ");
    Serial.println(tOnline);
    #endif
    outputDebugMessage("Synchronized time with the server!");
    // Adjust RTC with the webserver time
    DateTime new_now = DateTime(year(tOnline), month(tOnline), \
        day(tOnline), hour(tOnline), minute(tOnline), second(tOnline));
    rtc.adjust(new_now);
}

// Upload data file, broken into chunks, to the webserver
void uploadExistingData() {
    Dir dir = SPIFFS.openDir("/");
    while (dir.next()) {
        // Assumption: We only have relevant data
        String fileName = dir.fileName();
        int idx = fileName.indexOf('.');
        // We assume that the proper data file name is simply
        // the uid which has 8 characters (e.g. "/abcdef12.txt")
        if (idx == 9){
            // Only upload data of [uid].txt format
            eDNA_UID = fileName.substring(1, idx);    
    
            File curFile = dir.openFile("r");
            uint16_t fileSize = dir.fileSize();
            // We need to turn data into multiple chunks
            uint8_t nChunks = fileSize / CHUNK_SIZE + 1;
            samplerWiFi.uploadData(eDNA_UID, curFile, nChunks);
            // Delete the uploaded file
            SPIFFS.remove(fileName);
        }
    }
}


void uploadExistingLog() {
    if ((SPIFFS.exists(logFilePath)) && (eDNA_UID.length() != 0)) {        
        File logFile = SPIFFS.open(logFilePath, "r");
        uint16_t fileSize = logFile.size();
        // We need to turn data into multiple chunks
        uint8_t nChunks = fileSize / CHUNK_SIZE + 1;
        samplerWiFi.uploadInternalLog(eDNA_UID, logFile, nChunks);
        logFile.close();
        SPIFFS.remove(logFilePath);
    }
}

void outputDebugMessage(String msg) {
    #ifdef DEBUG
    Serial.println(msg);
    #endif
    internalLogLine(msg);
}

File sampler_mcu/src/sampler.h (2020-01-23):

/**
 * eDNA Sampler: ESP8266 based eDNA sampler / relevant sensor controller
 * sampler.h
 * January 2020
 * Authors: JunSu Jang
 *        
 *      [Descriptions]
 * Sampler is a class that that mainly handles the behavior of the device.
 * It verifies that the input deployment configuration is appropriate,
 * and lets the main system know when to trigger/pause the pump.
 */

#ifndef Sampler_h
#define Sampler_h

#include <cstdlib>
#include <stdint.h>
#include <limits.h>
#include <float.h>
#include "samplerGlobals.h"

// Pump condition global variables
#define N_START_COND 3          // Number of pump starting conditions
#define N_END_COND 3            // Number of pump ending conditions
#define NUM_FLOW_LOGS 5         // Num data for computing derivate of ticks
#define ABS_ZERO_C -273.15f     // default temperature value


class Sampler
{
    public:
        Sampler(void);
        // verifies that the user configuration provided is indeed valid
        uint8_t isValidUserConfig();
        // check to see if pump should be on/off
        uint8_t checkPumpTrigger(float depth, 
                                float temperature, 
                                uint32_t time_now, 
                                uint32_t ticks,
                                uint32_t pumpDuration);
        // set the deployment configuration variables
        void setDeploymentConfig(float minFlowrate, 
                                 float targetDepth,
                                 float depthBand,
                                 float targetTemperature,
                                 float temperatureBand,
                                 uint32_t waitPumpEnd,
                                 uint32_t waitPumpStart,
                                 uint32_t targetFlowVol,
                                 uint32_t ticksPerLiter);
        // set the dive start time (submerge below 2m)
        void setDiveStartTime(uint32_t diveStartTime);
        // set when the pump started
        void setPumpStartTime(uint32_t pumpStartTime);
        // keep track of the flowrate
        void updateCurrentFlowrate(uint32_t flowData);
        // compute the inital flowrate to help track the flowrate decline
        void computeMaxFlowrate(uint32_t flowData);
        // getter for the flowrate
        float getCurFlowrate(void);

    private:
        // user defined deployment configuration variables
        float _minFlowrate = MIN_FLOWRATE;         // L/min
        uint32_t _waitPumpEnd = UINT_MAX;          // seconds
        uint32_t _targetFlowVol = UINT_MAX;        // ticks 
        uint32_t _waitPumpStart = UINT_MAX;        // seconds after dive
        float _temperatureBand = 0.f;              // +/-100deg C pre-specified for maximum range
        float _targetTemperature = ABS_ZERO_C;     // deg Celcius
        float _depthBand = 0;                      // meters
        float _targetDepth = FLT_MAX;              // meters
        
        // Flowmeter information provided by the user
        uint32_t _ticksPerLiter = 0;               // ticks per Liter
        float _maxFlowrate = 0.f;                  // maximum flowrate

        // deployment pump trigger condition flags array
        // specifies which conditions are to be checked for in order to 
        // start and pause the pump
        uint8_t _startConditions[N_START_COND];    
        uint8_t _endConditions[N_END_COND];
        // masks are used to determine if any pump control condition has been met
        uint8_t _startConditionMask[N_END_COND];
        uint8_t _endConditionMask[N_START_COND];

        // unixtime to keep track of when the dive and pump started
        uint32_t _diveStartTime = UINT_MAX;
        uint32_t _pumpStartTime = UINT_MAX;

        // log of flow values for derivative calculation
        uint32_t _flowLog[NUM_FLOW_LOGS] = {0};
        // index of the currently accumulated ticks
        uint8_t _curFlowIdx = 0;
        // keep track of the flowrate internally
        float _curFlowrate = 0.f; 
};

#endif

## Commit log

2019-11-05 add flowmeter tick conversion
2019-11-07 cater to the new loggistics where the RFID will be tagged and power cycled
2020-01-14 update webapp fix with plots and offline code
    [eDNA_v0.ino]
2020-01-23 add battery, housing and pvc shell .step files as well as drawings
    [Battery Cap Bottom.stl, Battery Cap Top.stl, Battery Holder.stl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]
2020-01-23 add circuit schematics and layouts
    [eDNA_Sampler.brd, eDNA_Sampler.sch]
2020-01-23 refactor the code into a sampler_mcu directory
2020-01-23 update django framework
2020-01-25 add flowrate test
2020-02-14 update readme with documentation and current apparatus

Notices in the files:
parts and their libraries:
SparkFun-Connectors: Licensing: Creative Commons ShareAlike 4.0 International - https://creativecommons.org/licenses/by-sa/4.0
